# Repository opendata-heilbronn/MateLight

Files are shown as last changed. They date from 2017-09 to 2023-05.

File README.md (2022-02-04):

# Matelight

(https://opendata-heilbronn.github.io/MateLight/)

# Software Documentation
## [API](Raspberry_Pi/materix_API) Documentation
The Matelight "API" is written in nodeJS and can be used in other scripts.

### Scripts
Some scripts have already been created. They are located at [Raspberry_Pi/materix_API/api/scripts](Raspberry_Pi/materix_API/api/scripts).
- fromBitmap.js
    - Takes a bitmap and displays it on the Matelight
- testScroll.js
    - Displays a scrolling text on the Matelight
- glediatorBridge.js
    - Takes ArtNet packages and displays them on the matelight
    - Every crate row is one ArtNet universe. The channels start in the top left and travel down line wise
    - This mapping has to be set up in gLEDiator, or any other ArtNet sender
- pixelflut.js
    - exposes a [Pixelflut](https://cccgoe.de/wiki/Pixelflut) server on port 1337

Examples of how to launch the scripts can be found in the [scripts README](Raspberry_Pi/materix_API/api/scripts/README.md).

### Future plans
- HTTP API
- Create one central API that runs all the time and accepts input from multiple scripts

# Hardware Documentation
## Topology
The centerpiece of the installation is a Raspberry Pi with a USB to Serial adapter and a 12V server power supply.  
We didn't use the hardware serial of the Rapsberry Pi directly, because we already destroyed a Raspberry Pi by inducing voltage spikes or something like that.

### XLR pinout
The serial TX and 12V from the power supply get connected to the pins of a XLR plug like this:
1. +12V
2. GND
3. Serial Data

This plug is then connected to the first crate. 

We also made some intermediary cables to feed the power to multiple points in the matrix to reduce the current flowing through the XLR plugs.  
These were built just like normal pass-through cables, but with an extra XLR plug added for injecting 12V.

## Building a crate
### Materials needed

| Amount | Article | Approx. Price | Links |
| --- | --- | --- | --- |
| 1 | Club Mate Crate | 4.50€ |
| 1 | Arduino Pro Mini 5V | 1.50€ | [AliExpress](https://www.aliexpress.com/wholesale?SearchText=arduino+pro+mini+5v)  |
| 20/50 LEDs | 12mm WS2811 LED String | 5€ | [AliExpress](https://www.aliexpress.com/wholesale?SearchText=ws2811+12mm) |
| 1 | LM2596S Step Down | 1€ | [eBay](https://www.ebay.de/sch/i.html?_nkw=LM2596S) |
| 1 | XLR panel mount jack male | 2€ | [eBay](https://www.ebay.de/sch/i.html?_nkw=xlr+einbaubuchse+male) |
| 1 | XLR panel mount jack female | 2€ | [eBay](https://www.ebay.de/sch/i.html?_nkw=xlr+einbaubuchse+female) |
| 1 | XLR microphone cable 0.5m | 3€ | [eBay](https://www.ebay.de/sch/i.html?_nkw=0%2C5m+mikrofonkabel) |
| 24/40 pins | Female header | 0.10€ | [AliExpress](https://www.aliexpress.com/wholesale?SearchText=female+header+40+pin) |
| Some | Plywood | |
| Some | Cardboard | |

### Instructions

1. Clean out all bottles
2. Wrap the bottles in aluminum foil and secure it with tape
3. Put a LED into each bottle following this pattern:  
    ```
            (seen from back, ↥ top ↥)
           ╔═══════════════════════════╗
           ║ ○  →  ○     ○  →  ○     ○ ║ →{out}
           ║ ↑     ↓     ↑     ↓     ↑ ║
           ║ ○     ○     ○     ○     ○ ║
           ║ ↑     ↓     ↑     ↓     ↑ ║
           ║ ○     ○     ○     ○     ○ ║
           ║ ↑     ↓     ↑     ↓     ↑ ║
    {in} → ║ ○     ○  →  ○     ○  →  ○ ║
           ╚═══════════════════════════╝
                   (↧ bottom ↧)
    ```
4. Solder female headers for the Arduino to a piece of prototyping board
5. Build the wooden back plate (schematics coming soon)
6. Drill holes and screw the XLR Sockets in (male left, female right)
7. Glue the buck converter and prototyping board from the inside to the wood
8. Follow the [wiring steps](docs/img/wiringStepByStep/README.md)
9. Put cardboard padding between the bottles and the wood plate
10. Screw the wood plate onto the crate
11. Flash the firmware onto the Arduino 
    - chose the correct firmware from [Crate_Arduino_Receiver](Hardware/Crate_Arduino_Receiver) by the amount of bottles in a crate
12. Connect all crates together with XLR cables in a serpentine pattern like this:
    ```
                 (back side of array)
           [ ] → [ ] → [ ] → [ ] → [ ] → [ ] → [ ]
            ↑
           [ ] ← [ ] ← [ ] ← [ ] ← [ ] ← [ ] ← [ ]   (<- this row of crates is flipped 180°)
                                                ↑
    {in} → [ ] → [ ] → [ ] → [ ] → [ ] → [ ] → [ ]
    ```

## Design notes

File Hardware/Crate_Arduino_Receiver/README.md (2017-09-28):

# receiver

Have a look to matelight.de for understanding, where the receiver is placed.

A receiver is taking a input-array of numbers from 0 to 255. The receiver will take the first 20\*3 entries of this array and send all others by using the serial out pin (tx0).

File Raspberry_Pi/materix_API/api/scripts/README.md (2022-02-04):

# Script launch examples

`node testScroll.js --device=/dev/ttyUSB0 --width=7 --height=3 --orientation=landscape --text="Alle Kaesten tun!"`

`node fromBitmap.js --url=https://raw.githubusercontent.com/matelighthn/matelighthn.github.io/master/ILoveMatelight.png --device=/dev/ttyUSB0 --width=7 --height=3 --orientation=landscape`

`node glediatorBridge.js -w 7 -h 3 -d /dev/ttyUSB0`

`node testScroll.js -w 10 -h 2 -t "hello world" -d sim`

`node pixelflut.js -w 7 -h 3`

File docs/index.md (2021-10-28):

# Was ist das MateLight?

Das MateLight ist eine interaktive LED-Installation. Es besteht aus RGB-LEDs und Club-Mate-Kästen. 
Damit ergibt sich ein Raster mit bunten Punkten. Also quasi ein Display.

Das MateLight ist klassischer Nerd-Shit. Es erfüllt keinen wirklich sinnvollen Zweck und wurde geschaffen, weil man es kann.
Aber für ein paar Dinge kann man es schon verwenden. Es kann z.B. hervoragend als Effektbeleuchtung bei Veranstaltungen
eingesetzt werden. Außerdem ist es ein tolles Spielzeug für Programmier-Padawane. Man jage ein paar Zahlen hinein
und betrachte die bunt blinkende Welt.

# Wo kann ich das MateLight sehen?
 
Auf der MakerFaire in Hannover

Oder an jedem Coding-Donnerstag im [Maker Space](https://makerspace.experimenta.science)

# Made at code for Heilbronn</h2>



Das MateLight wurde von den Teilnehmern der Coding-Abende bei [CodeFor Heilbronn](https://codeforheilbronn.de/) entwickelt und hergestellt.

# Contributors

img/contributors/theVale98.jpg
* TheVale98
    * Hardware

img/contributors/LeoDJ.jpg
* LeoDJ
    * Hardware, Software

img/contributors/Franz.jpg

* Franz
    * Hardware

'img/contributors/harmoniemand.jpg
* Jonathan
    * Software

# Wie kann ich helfen?

Hilfe können wir immer brauchen um neue Kästen zu bauen. Dazu sollte man löten können.
Wir treffen und immer Donnerstags. Zwar wird nicht immer und ausschließlich am MateLight gearbeitet, aber 
immer öfter.

Außerdem kann das MateLight um coole neue Funktionen erweitert werden. Seien es Spiele oder der geplante Webservice.
Dazu sollte man NodeJS oder Arduino (C++) programmieren können.

# Software Documentation
## [API](Raspberry_Pi/materix_API) Documentation
The Matelight "API" is written in nodeJS and can be used in other scripts.

### Scripts
Some scripts have already been created. They are located at [Raspberry_Pi/materix_API/api/scripts](Raspberry_Pi/materix_API/api/scripts).
- fromBitmap.js
    - Takes a bitmap and displays it on the Matelight
- testScroll.js
    - Displays a scrolling text on the Matelight
- glediatorBridge.js
    - Takes ArtNet packages and displays them on the matelight
    - Every crate row is one ArtNet universe. The channels start in the top left and travel down line wise
    - This mapping has to be set up in gLEDiator, or any other ArtNet sender

Examples of how to launch the scripts can be found in the [scripts README](Raspberry_Pi/materix_API/api/scripts/README.md).

### Future plans
- PixelFlut API
- HTTP API
- Create one central API that runs all the time and accepts input from multiple scripts

# Hardware Documentation
## Topology
The centerpiece of the installation is a Raspberry Pi with a USB to Serial adapter and a 12V server power supply.  
We didn't use the hardware serial of the Rapsberry Pi directly, because we already destroyed a Raspberry Pi by inducing voltage spikes or something like that.

### XLR pinout
The serial TX and 12V from the power supply get connected to the pins of a XLR plug like this:
1. +12V
2. GND
3. Serial Data

This plug is then connected to the first crate. 

We also made some intermediary cables to feed the power to multiple points in the matrix to reduce the current flowing through the XLR plugs.  
These were built just like normal pass-through cables, but with an extra XLR plug added for injecting 12V.

## Building a crate
### Materials needed

| Amount | Article | Approx. Price | Links |
| --- | --- | --- | --- |
| 1 | Club Mate Crate | 4.50€ |
| 1 | Arduino Pro Mini 5V | 1.50€ | [AliExpress](https://www.aliexpress.com/wholesale?SearchText=arduino+pro+mini+5v)  |
| 20/50 LEDs | 12mm WS2811 LED String | 5€ | [AliExpress](https://www.aliexpress.com/wholesale?SearchText=ws2811+12mm) |
| 1 | LM2596S Step Down | 1€ | [eBay](https://www.ebay.de/sch/i.html?_nkw=LM2596S) |
| 1 | XLR panel mount jack male | 2€ | [eBay](https://www.ebay.de/sch/i.html?_nkw=xlr+einbaubuchse+male) |
| 1 | XLR panel mount jack female | 2€ | [eBay](https://www.ebay.de/sch/i.html?_nkw=xlr+einbaubuchse+female) |
| 1 | XLR microphone cable 0.5m | 3€ | [eBay](https://www.ebay.de/sch/i.html?_nkw=0%2C5m+mikrofonkabel) |
| 24/40 pins | Female header | 0.10€ | [AliExpress](https://www.aliexpress.com/wholesale?SearchText=female+header+40+pin) |
| Some | Plywood | |
| Some | Cardboard | |

### Instructions

1. Clean out all bottles
2. Wrap the bottles in aluminum foil and secure it with tape
3. Put a LED into each bottle following this pattern:  
    ```
            (seen from back, ↥ top ↥)
           ╔═══════════════════════════╗
           ║ ○  →  ○     ○  →  ○     ○ ║ →{out}
           ║ ↑     ↓     ↑     ↓     ↑ ║
           ║ ○     ○     ○     ○     ○ ║
           ║ ↑     ↓     ↑     ↓     ↑ ║
           ║ ○     ○     ○     ○     ○ ║
           ║ ↑     ↓     ↑     ↓     ↑ ║
    {in} → ║ ○     ○  →  ○     ○  →  ○ ║
           ╚═══════════════════════════╝
                   (↧ bottom ↧)
    ```
4. Solder female headers for the Arduino to a piece of prototyping board
5. Build the wooden back plate (schematics coming soon)
6. Drill holes and screw the XLR Sockets in (male left, female right)
7. Glue the buck converter and prototyping board from the inside to the wood
8. Follow the [wiring steps](docs/img/wiringStepByStep/README.md)
9. Put cardboard padding between the bottles and the wood plate
10. Screw the wood plate onto the crate
11. Flash the firmware onto the Arduino 
    - chose the correct firmware from [Crate_Arduino_Receiver](Hardware/Crate_Arduino_Receiver) by the amount of bottles in a crate
12. Connect all crates together with XLR cables in a serpentine pattern like this:
    ```
                 (back side of array)
           [ ] → [ ] → [ ] → [ ] → [ ] → [ ] → [ ]
            ↑
           [ ] ← [ ] ← [ ] ← [ ] ← [ ] ← [ ] ← [ ]   (<- this row of crates is flipped 180°)
                                                ↑
    {in} → [ ] → [ ] → [ ] → [ ] → [ ] → [ ] → [ ]
    ```

# Wiring Instructions Step by Step
Start with the following plywood plate:

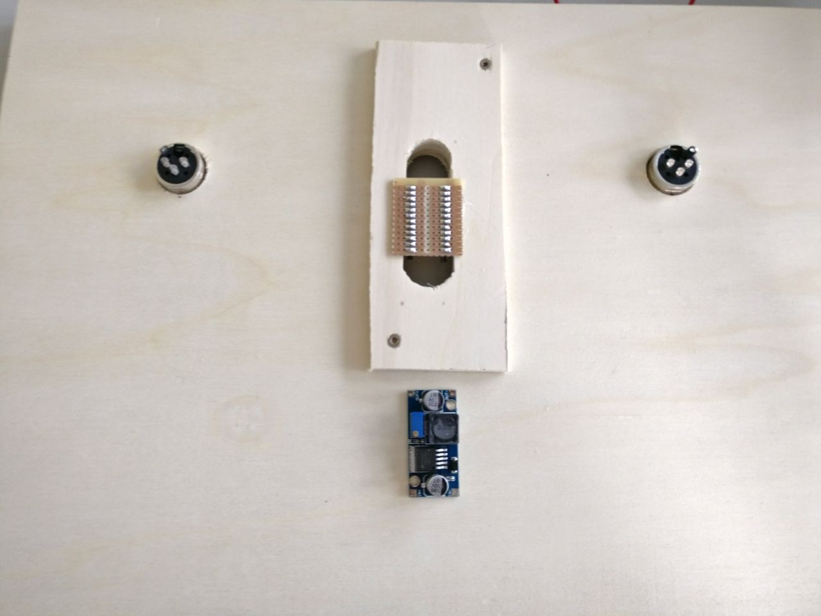
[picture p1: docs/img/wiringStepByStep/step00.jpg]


### Step 1
Connect the 12V power passthrough cable

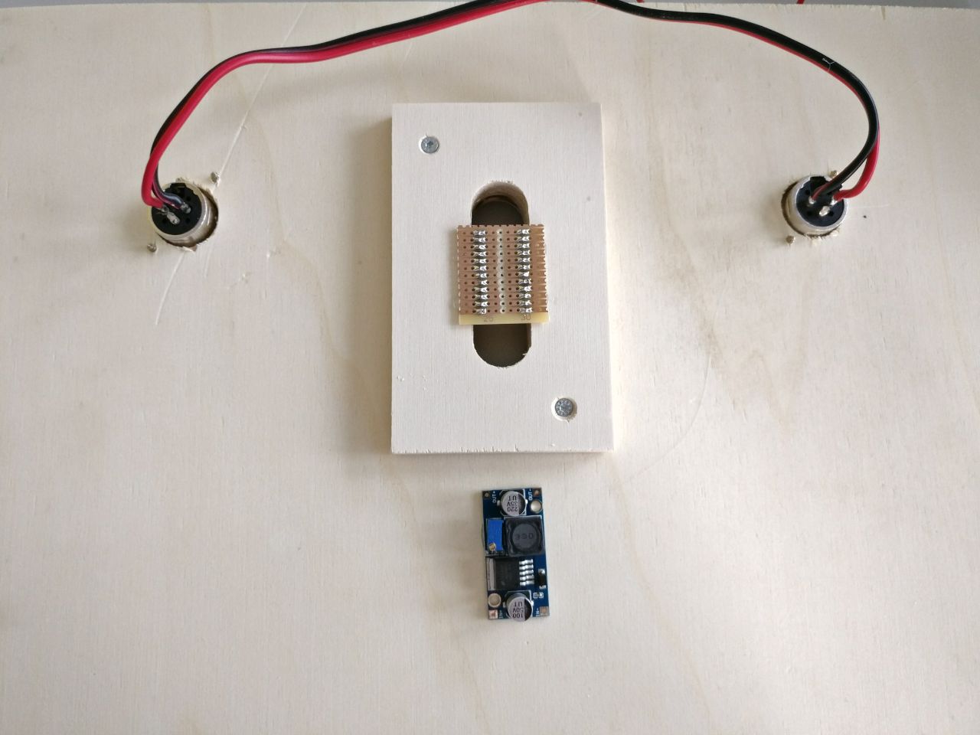
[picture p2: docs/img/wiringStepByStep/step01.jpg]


### Step 2
Connect the 12V power from the XLR input

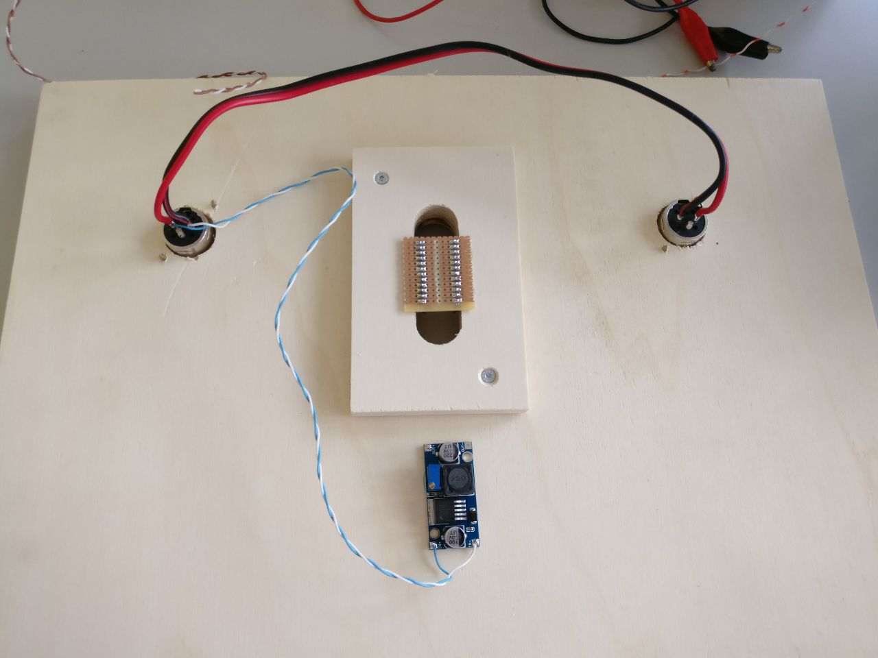
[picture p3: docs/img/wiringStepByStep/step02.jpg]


### Step 3
Connect the regulated 5V to the Arduino 5V/VCC pin

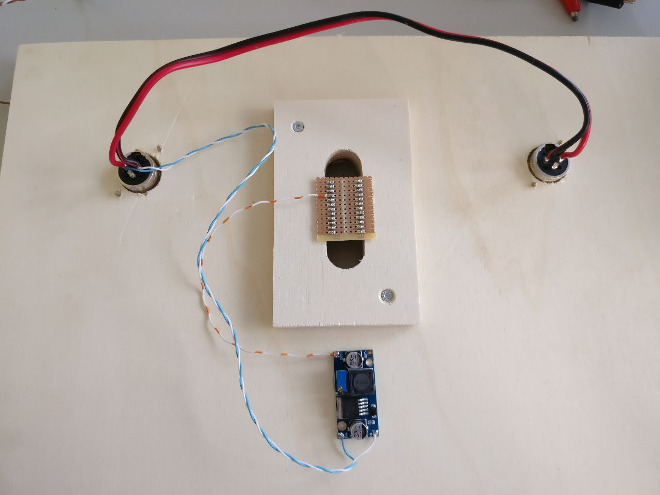
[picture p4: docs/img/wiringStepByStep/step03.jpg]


### Step 4
Connect XLR data in and GND to Arduino RX and GND pins

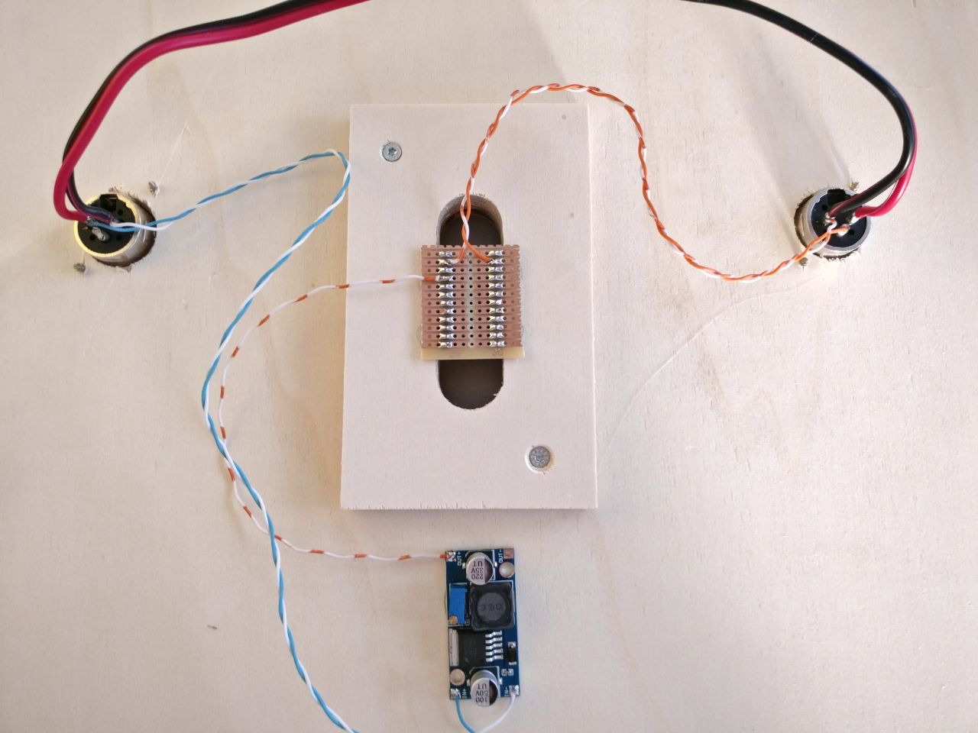
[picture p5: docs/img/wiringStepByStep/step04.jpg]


### Step 5
Connect the Arduino TX pin to XLR data out

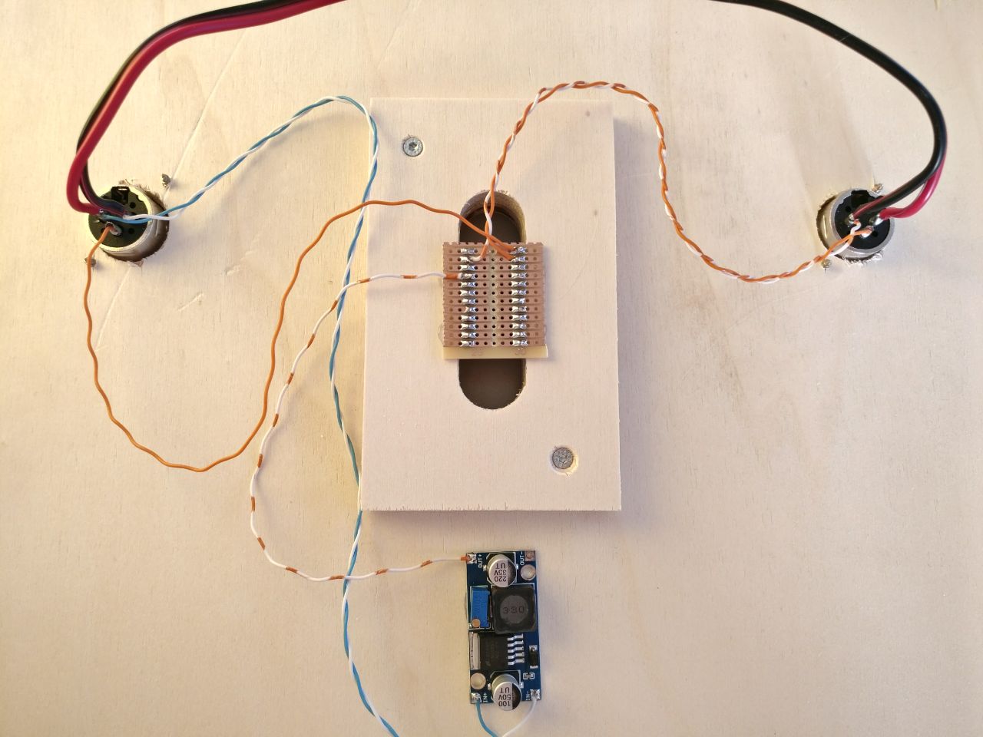
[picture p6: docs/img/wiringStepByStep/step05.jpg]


### Step 6
Connect the 5V power wires for the LEDs to the buck converter

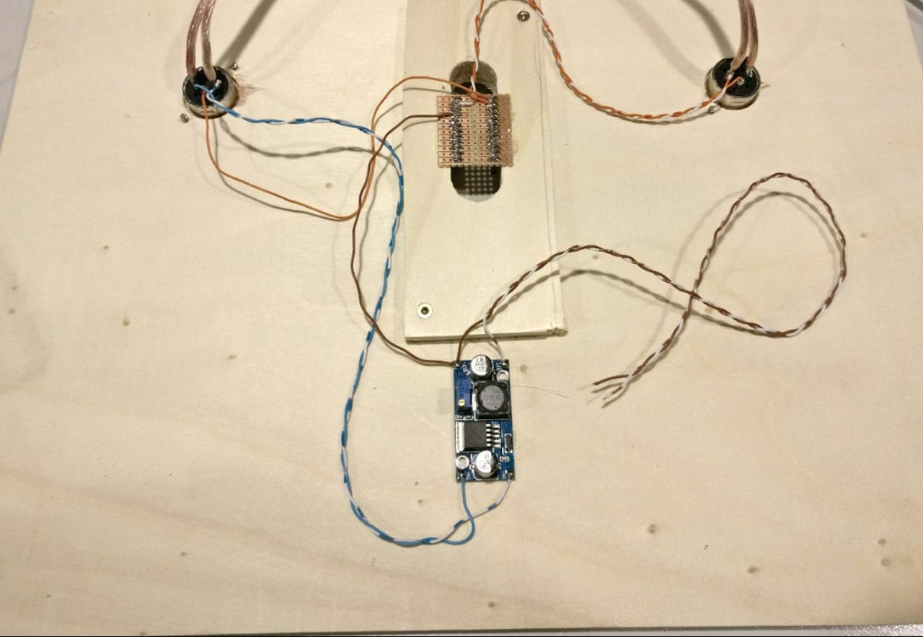
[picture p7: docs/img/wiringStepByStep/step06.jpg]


### Step 7
Connect the LED data wire to Arduino pin 2
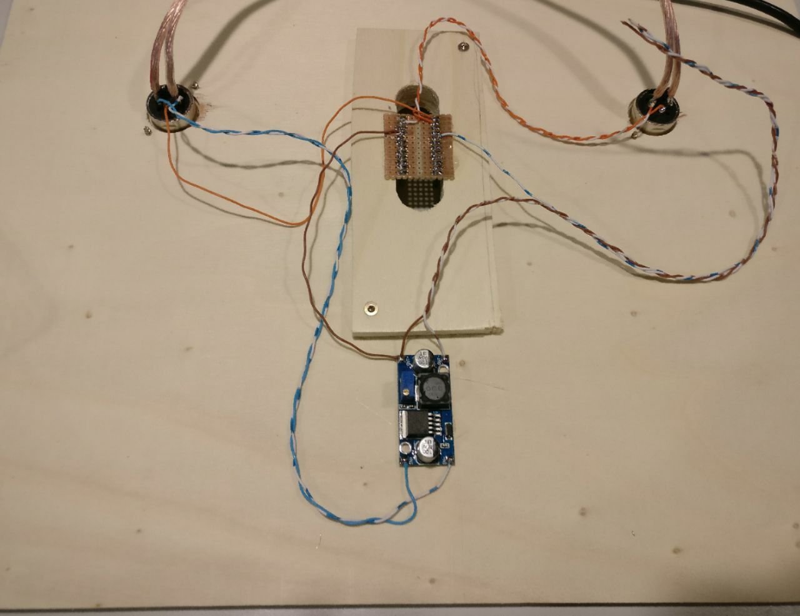
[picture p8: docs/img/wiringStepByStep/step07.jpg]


### Step 8
Connect the three open cables from step 7 to the input of LED string accordingly

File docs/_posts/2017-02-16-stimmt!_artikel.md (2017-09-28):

---
layout: blog_entry
headline: Bericht über CodeFor und das MateLight in der Stimmt! Heilbronn
tags: [materix, arduino, zeitung]
permalink: /blog/:year:month:day-:title
published: true
caption: Guter Artikel über CodeFor Heilbronn in der Zeitung.
---

http://www.stimmt.de/news/webreporter/vorort/2017/februar/art6257,96647

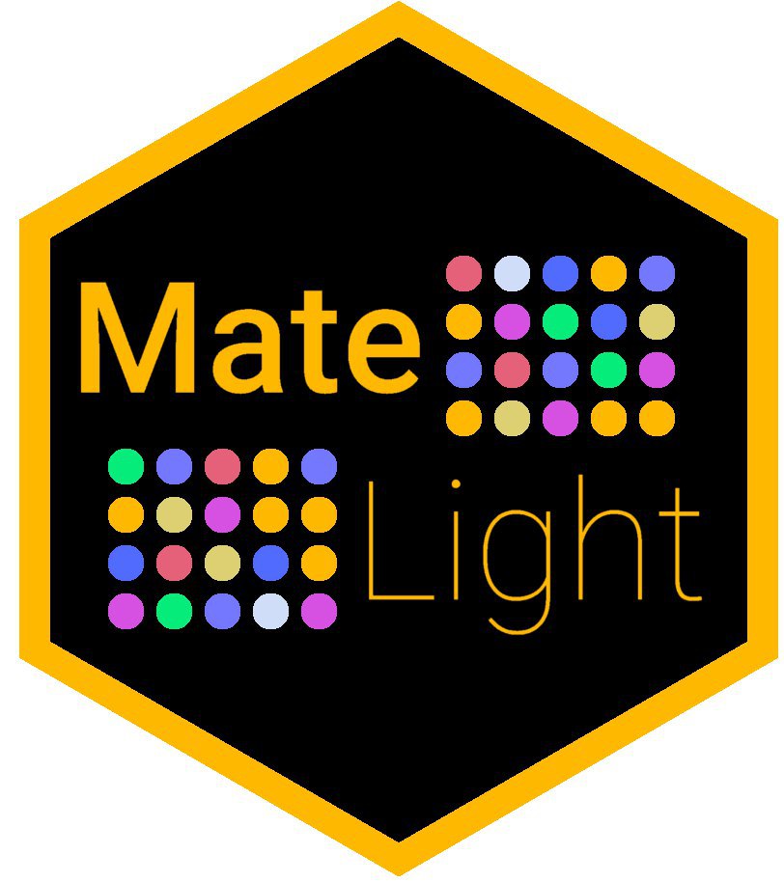
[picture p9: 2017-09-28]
docs/img/sticker.jpg

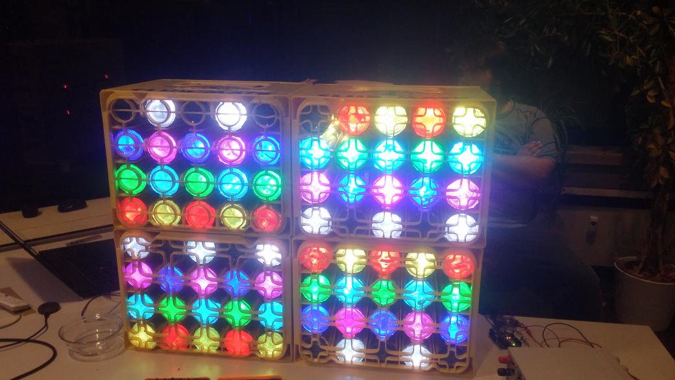
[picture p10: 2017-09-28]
docs/img/header.jpg

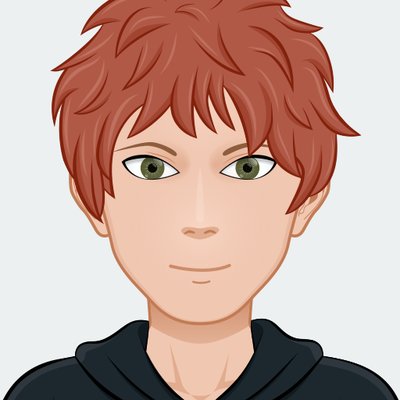
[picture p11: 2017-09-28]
docs/img/contributors/LeoDJ.jpg

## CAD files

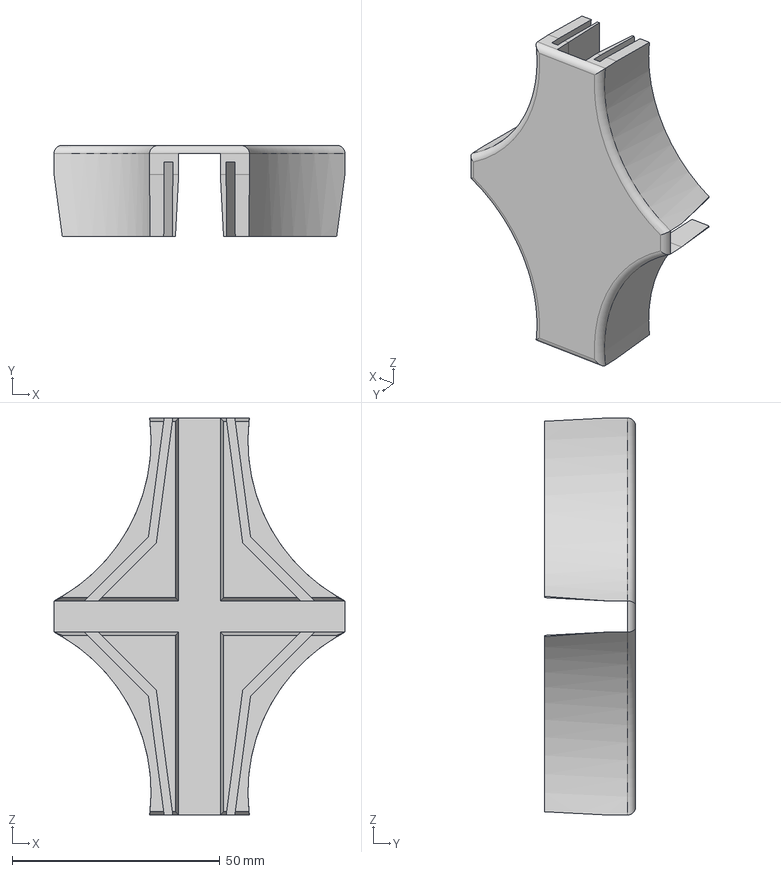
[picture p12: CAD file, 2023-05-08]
Matekiste-Verbinder.stp
70.0 x 22.0 x 95.5 mm

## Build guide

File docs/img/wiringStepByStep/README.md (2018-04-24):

# Wiring Instructions Step by Step
Start with the following plywood plate:



### Step 1
Connect the 12V power passthrough cable



### Step 2
Connect the 12V power from the XLR input



### Step 3
Connect the regulated 5V to the Arduino 5V/VCC pin



### Step 4
Connect XLR data in and GND to Arduino RX and GND pins



### Step 5
Connect the Arduino TX pin to XLR data out



### Step 6
Connect the 5V power wires for the LEDs to the buck converter



### Step 7
Connect the LED data wire to Arduino pin 2


### Step 8
Connect the three open cables from step 7 to the input of LED string accordingly

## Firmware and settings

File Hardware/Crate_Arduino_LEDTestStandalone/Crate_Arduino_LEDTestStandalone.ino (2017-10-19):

#include "FastLED.h"

const int NUM_LEDS = 24;
const int DATA_PIN = 2;

CRGB leds[NUM_LEDS];

void setup() {
  FastLED.addLeds<WS2811, DATA_PIN, RGB>(leds, NUM_LEDS);
}


void loop() {
  for(byte i = 0; i < NUM_LEDS; i++) {
    byte hue = map(i, 0, NUM_LEDS-1, 0, 255) + millis()/50;
    leds[i] = CHSV(hue, 255, 255);
  }
  FastLED.show();
  delay(50);
}

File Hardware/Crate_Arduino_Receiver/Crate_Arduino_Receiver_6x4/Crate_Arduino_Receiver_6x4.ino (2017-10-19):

#include "FastLED.h"

#define NUM_LEDS 24
#define NUM_BYTES NUM_LEDS*3

const int DATA_PIN = 2;
const int timeout = 500;

unsigned char inputBuffer[NUM_BYTES];
unsigned char inCounter=0;

unsigned long lastPacket=0;

CRGB leds[NUM_LEDS];

void setup() {
  Serial.begin(500000);
  FastLED.addLeds<WS2811, DATA_PIN, RGB>(leds, NUM_LEDS);
}

void parseBuffer()
{
  for (byte i = 0; i < NUM_BYTES; i++)
  {
    leds[i/3][i%3] = inputBuffer[i];
  }
}



void loop() {
  if(Serial.available()) //this method _should_(tm) be a better way of handling high speed Serial input without swallowing bytes
  {
    for(byte i = 0; i < Serial.available(); i++)
    {
      unsigned char incomingByte = Serial.read();
      if(inCounter < NUM_BYTES)
      {
        inputBuffer[inCounter] = incomingByte;
        inCounter++;
      }
      else
      {
        Serial.write(incomingByte);
      }
    }
    lastPacket = micros();
  }

  if(micros() - lastPacket > timeout && inCounter > 0)
  {
    inCounter = 0;
    parseBuffer();
    FastLED.show();
  }
}

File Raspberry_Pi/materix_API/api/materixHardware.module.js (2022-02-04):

var SerialPort = require('serialport');
var NanoTimer = require('nanotimer');
var port;

var isOpen = false;

function constructor(opts) {
    if(opts.baudRate == undefined) throw new Error('no baudrate supplied');
    if(opts.serialDevice == undefined) throw new Error('no serialDevice supplied');


    port = new SerialPort(opts.serialDevice, {
        baudRate: opts.baudRate
    });

    port.on('error', function(err){
        throw err;
    });

    port.on('open', function() {
    });

    port.on('disconnect', function(e) {
        console.log("Serial port disconnected");
    })
}

function sendPixels(rawData, callback) { //accepts a flat byte array
    if(port.isOpen) {
        port.write(rawData, function(err){ //TODO: check if works, maybe wants a buffer insetead of array
            if(err) {
                throw new Error(err);
            }
        });
        port.drain(callback); //waits until all data is written before calling callback
    }
    else throw new Error('port is not open (yet)');
}

function close() {
    port.close();
}

module.exports = function(opts) {
    constructor(opts);
    return {
        sendPixels,
        isReady: () => port.isOpen(),
        close
    }
}

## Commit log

2017-02-10 current state [does not work]
2017-02-11 implement led mapping generation
2017-02-24 reducing the baud rate helped much in terms of stability
    [materixHardware.module.js]
2017-03-15 fix ledMap in unit test
2018-04-26 pause socket during data write
